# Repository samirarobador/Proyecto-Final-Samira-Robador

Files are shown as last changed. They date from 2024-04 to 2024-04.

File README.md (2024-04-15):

# Brazo Robótico Dispensador de Sustancias Químicas

El Laboratorio de Alta Complejidad de la Universidad Nacional de Chilecito, desempeña un papel vital en la ejecución de  análisis esenciales para la investigación y empresas. No obstante, actualmente  se enfrenta a limitaciones significativas relacionadas con la dosificación manual de sustancias químicas. Con el objetivo de abordar esta problemática y potenciar la precisión como así también la eficiencia en la manipulación de sustancias químicas, este proyecto propone automatizar el proceso mediante un brazo robótico especializado. Esta solución mejorará la precisión y eficiencia en la manipulación de sustancias químicas, agilizando análisis y reduciendo las posibilidades de errores. 

Este repositorio contiene el código fuente para un sistema de control de dosificación de sustancias químicas implementado con Python y Django, y con una interfaz de usuario basada en HTML, CSS y JavaScript. Permite la manipulación y control remoto de un robot dosificador a través de una interfaz web.

## Comenzando

Estas instrucciones te permitirán obtener una copia del proyecto en funcionamiento en tu máquina local para propósitos de desarrollo y pruebas.

### Prerrequisitos

Necesitarás Python y Django instalados en tu sistema para poder ejecutar el proyecto. Asegúrate también de tener instalado Git para clonar el repositorio.

```bash
# Instalar Git
sudo apt-get install git

# Instalar Python (el comando puede variar dependiendo de tu sistema operativo)
sudo apt-get install python3

# Instalar Django
pip install django
```

## Instalación
Clona el repositorio en tu máquina local usando Git.

```bash
git clone https://github.com/samirarobador/Proyecto-Final-Samira-Robador.git
cd Proyecto-Final-Samira-Robador/mi_proyecto
```

## Levantar la Aplicación
Para iniciar la aplicación, ejecuta el servidor de desarrollo de Django con el siguiente comando:

```bash
python manage.py runserver
```

Una vez que el servidor esté funcionando, podrás acceder a la aplicación a través de tu navegador web en localhost:8000/.

## Despliegue
Este proyecto está configurado para ser ejecutado en un entorno de desarrollo. Para despliegues en producción, se deben realizar configuraciones adicionales, siguiendo las mejores prácticas de seguridad y rendimiento recomendadas por Django.

## Construido Con
- Python - El lenguaje de programación utilizado.
- Django - El framework web.
- HTML5, CSS3, y JavaScript - Para la interfaz de usuario.

## Autor

([Samira Robador](https://github.com/samirarobador)) - Trabajo Final

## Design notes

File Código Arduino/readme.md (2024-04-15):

# Configuración de placa ESP32

Este repositorio contiene el archivo de configuración `.ino` para la manipulación de un brazo robótico. Este script en particular se encarga de configurar y manejar el brazo robótico, conectarlo a la red Wi-Fi, y ajustar parámetros esenciales para su operación.

## Contenido del Repositorio

- **RoboticArm.ino**: Archivo principal que contiene todo el código necesario para la configuración inicial del brazo robótico, la conexión Wi-Fi y la manipulación de sus articulaciones.

## Requisitos

Para utilizar este archivo, necesitarás:

- **Arduino IDE**: Para cargar el código al microcontrolador.
- **Módulo ESP32**: Este código está diseñado para microcontroladores ESP32.

## Instalación

1. Descarga e instala el Arduino IDE desde [la página oficial de Arduino](https://www.arduino.cc/en/software).
2. Clona este repositorio en tu computadora local o descarga el archivo `RobotDispensador.ino` directamente.
3. Abre el archivo `RobotDispensador.ino` con Arduino IDE.
4. Conecta tu módulo ESP32 a tu computadora mediante un cable USB.
5. Selecciona el modelo correcto de tu ESP32 en el menú de Herramientas > Placa de Arduino IDE.
6. Compila y sube el código al ESP32 seleccionando "Subir" en el Arduino IDE.

## Configuración de Wi-Fi

El archivo `RobotDispensador.ino` contiene secciones claramente marcadas para configurar tu red Wi-Fi. Asegúrate de actualizar las siguientes líneas con tus datos de acceso a Wi-Fi:

```c++
const char* ssid = "TU_SSID";
const char* password = "TU_CONTRASEÑA";

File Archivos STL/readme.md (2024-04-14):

# Brazo Robótico 3D

Este repositorio contiene los archivos STL necesarios para imprimir un el Brazo Robótico Dispensador de Sustancias Químicas completo en una impresora 3D. Cada archivo representa una pieza específica del brazo robótico, diseñado para ser fácilmente ensamblable y funcional, además de las estructuras adicionales detalladas en el Proyecto Final.

## Contenido del Repositorio

Dentro de este repositorio, encontrarás los siguientes archivos STL:

- `basefija.stl` - La base del brazo robótico.
- `basegiratoria.stl` - La base giratoria del brazo robótico.
- `antebrazo.stl` - El antebrazo del brazo robótico.
- `brazo.stl` - La articulación del brazo.
- `muñeca.stl` - La muñeca, que conecta el brazo con la manguera de dispensación.
- `soportegradilla.stl` - El soporte gradilla, corresponde a la estructura adicional desarrollada para la grilla original.
- `basegradillaizq.stl` - La basegradilla izq corresponde a la estructura básica de la gradilla en coordenadas polares.
- `basegradillader.stl` - La basegradilla der corresponde a la estructura básica de la gradilla en coordenadas polares.
- `gradillaizq.stl` - La gradilla izq corresponde a la estructura principal de la gradilla en coordenadas polares.
- `gradillader.stl` - La gradilla der corresponde a la estructura principal de la gradilla en coordenadas polares.

## Instrucciones de Impresión

### Materiales Recomendados

- PLA/ABS para una mayor durabilidad.
- Soportes para algunas piezas que podrían requerirlo debido a la complejidad de su diseño.

### Configuración de Impresión

- Resolución: 0.2 mm para un buen equilibrio entre tiempo de impresión y detalle.
- Relleno: 20% para asegurar la durabilidad sin usar demasiado material.
- Soportes: Según sea necesario, especialmente para piezas con voladizos o puentes.

## Montaje

Después de imprimir todas las piezas, siga las instrucciones paso a paso para el ensamblaje del brazo robótico. Se recomienda verificar y limar cualquier parte que pueda tener excesos de material o hilos para un ensamblaje suave.

## Contacto

Si tiene preguntas o necesita ayuda con los archivos, no dude en contactarme a [samirarobador@gmail.com](mailto:samirarobador@gmail.com).

---

Espero que disfrute construyendo y utilizando este brazo robótico. Por favor, comparta sus modificaciones y mejoras para que otros puedan beneficiarse de su trabajo.

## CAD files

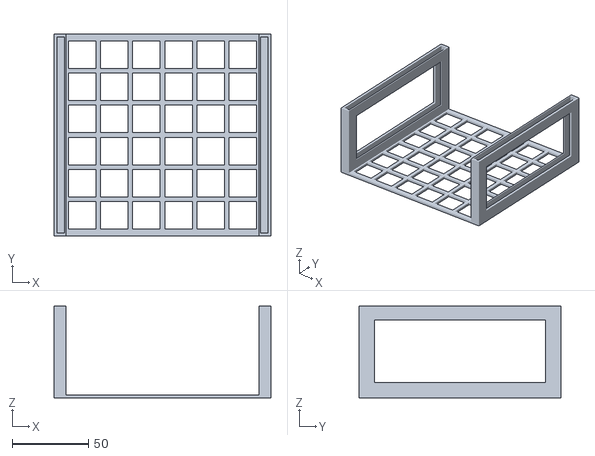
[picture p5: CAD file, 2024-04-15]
Archivos STL/Soporte adaptado Gradilla.stl
142.0 x 132.0 x 60.0

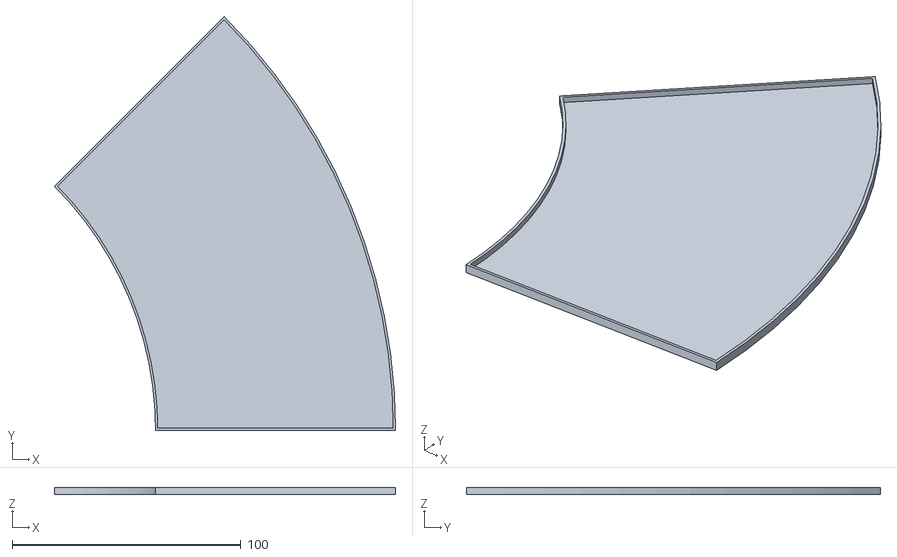
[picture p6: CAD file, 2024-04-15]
Archivos STL/Base Gradilla Nueva.stl
149.2 x 181.0 x 3.00

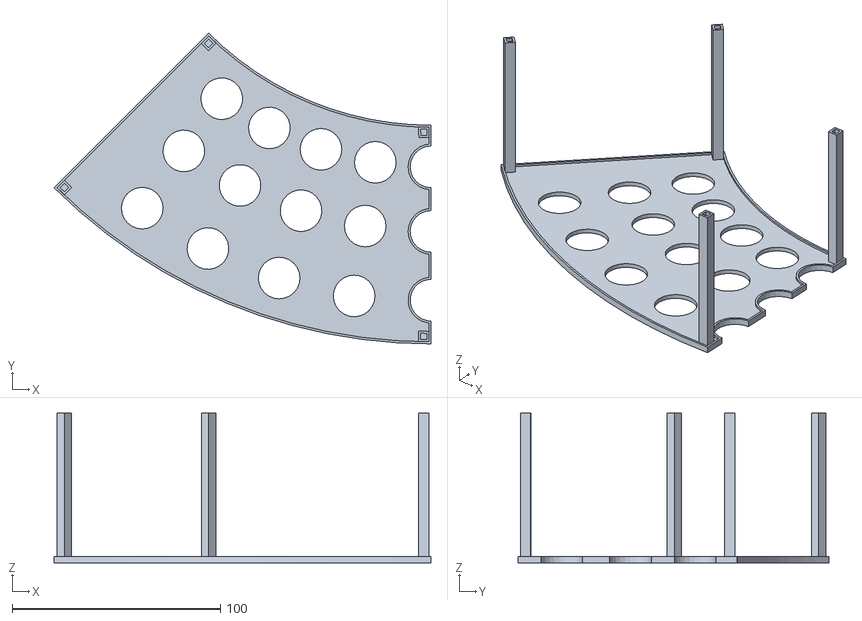
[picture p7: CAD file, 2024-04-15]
Archivos STL/Gradilla Nueva 2.stl
181.0 x 149.2 x 72.0

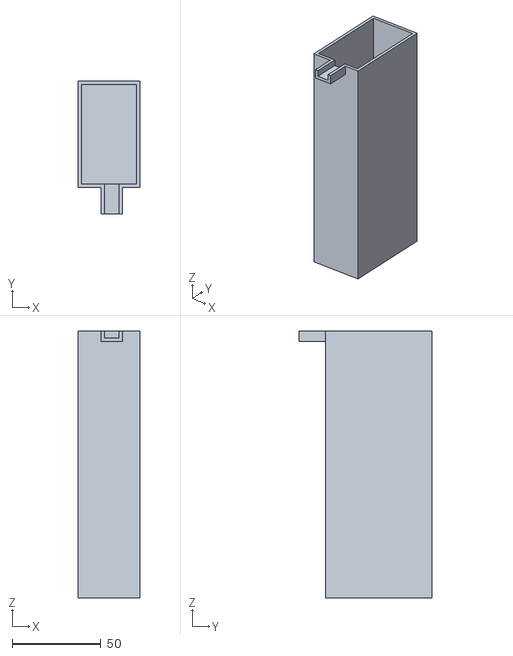
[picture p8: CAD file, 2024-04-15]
Archivos STL/Vaso Purgado.stl
35.0 x 75.0 x 150.0

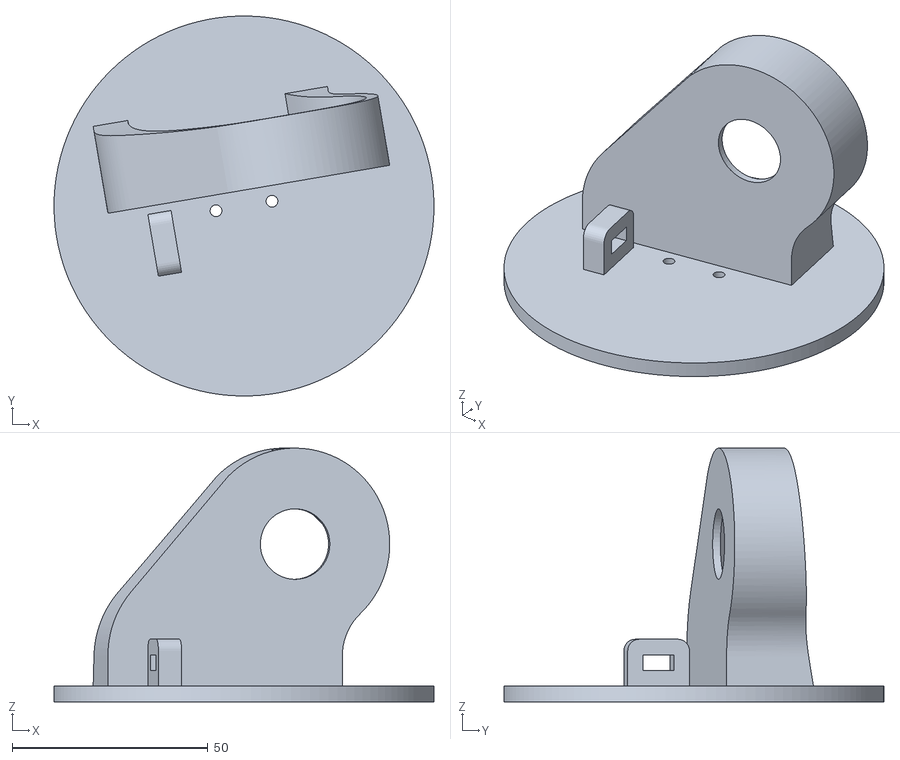
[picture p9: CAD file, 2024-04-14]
Archivos STL/Base Giratoria.stl
97.0 x 97.0 x 64.8

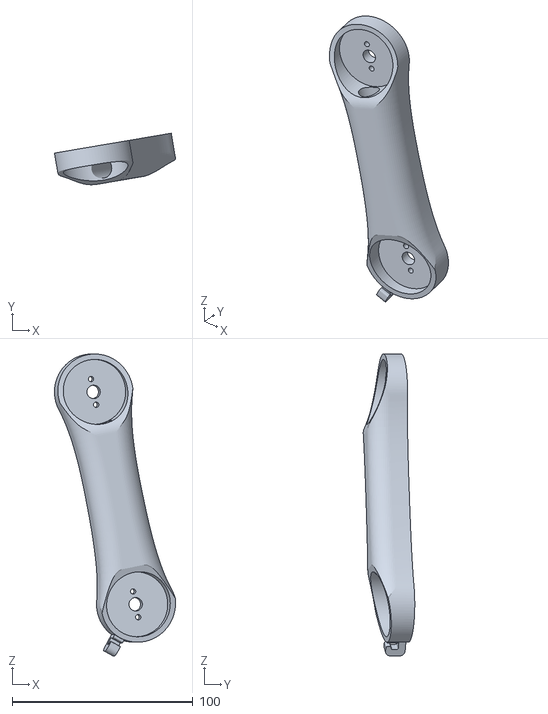
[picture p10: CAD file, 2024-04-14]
Archivos STL/Brazo.stl
67.1 x 28.6 x 167.3

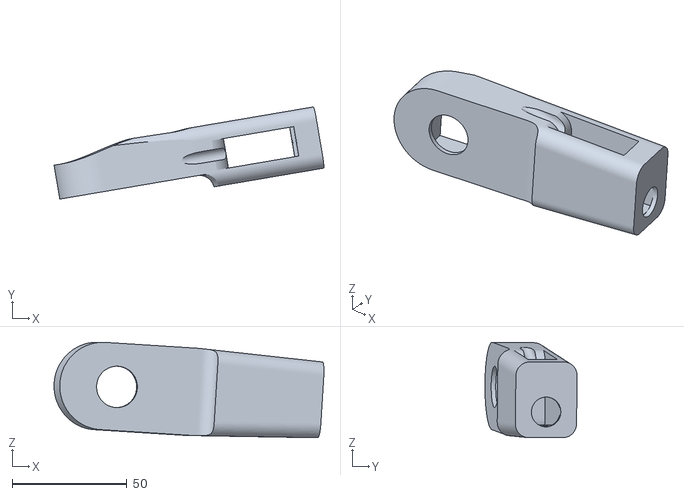
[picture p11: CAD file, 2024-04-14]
Archivos STL/Antebrazo.stl
117.4 x 40.1 x 41.5

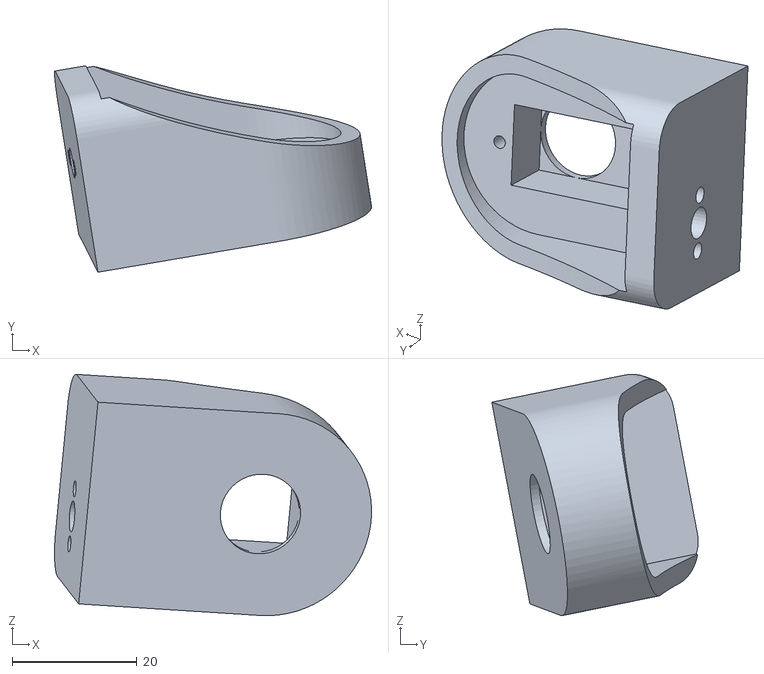
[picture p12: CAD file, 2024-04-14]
Archivos STL/Extremo.stl
50.7 x 33.0 x 38.6

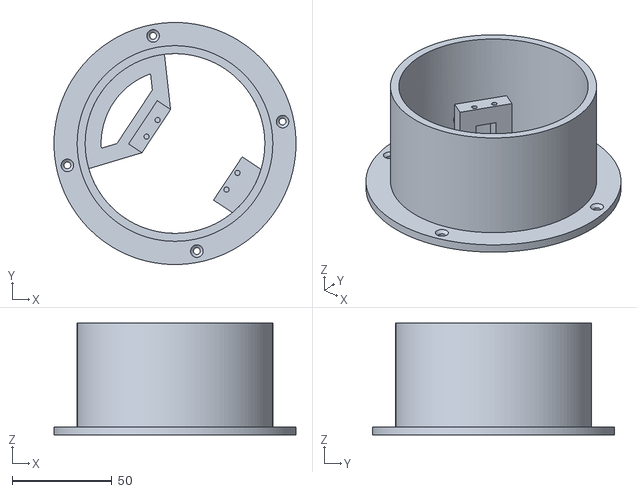
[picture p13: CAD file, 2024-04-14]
Archivos STL/Base.stl
121.2 x 121.2 x 56.0

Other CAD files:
Archivos STL/Gradilla Nueva 1.stl

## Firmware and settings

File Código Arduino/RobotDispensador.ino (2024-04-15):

#include <WiFi.h>
#include <ESPAsyncWebServer.h>
#include <ESP32Servo.h>
#include <HTTPClient.h>
#include <stdlib.h>
#include <math.h>
#include <stdio.h>

const char *ssid = "aquinombredered";
const char *password = "aquipassdered";

const int bombaPin = 25; // Pin al que está conectado Servo1

const int servoPin1 = 12; // Pin al que está conectado Servo1
const int servoPin2 = 14; // Pin al que está conectado Servo2
const int servoPin3 = 27; // Pin al que está conectado Servo3
const int servoPin4 = 26; // Pin al que está conectado Servo4

float q1Valor = 85;
float q2Valor = 160;
float q3Valor = 162;
float q4Valor = 87;

int maxServo = 2540;
int minServo = 440;


Servo servo1; // Declarar el objeto servo1
Servo servo2; // Declarar el objeto servo2
Servo servo3; // Declarar el objeto servo2
Servo servo4; // Declarar el objeto servo2
HTTPClient http;
AsyncWebServer server(80);

void moverGradualmenteServo(Servo &servo, float targetAngle) {
  float currentAngle = servo.read(); // Leer el ángulo actual del servo
  Serial.print("Valor actual del Servo: ");
  Serial.println(currentAngle);
  float step = (targetAngle > currentAngle) ? 1 : -1; // Determinar el paso de incremento o decremento

  // Mover gradualmente el servo hacia el ángulo deseado
  while (currentAngle != targetAngle) {
    currentAngle = currentAngle + step; // Incrementar o decrementar el ángulo actual
    servo.write(currentAngle); // Enviar el nuevo ángulo al servo
    delay(10); // Pequeña pausa para suavizar el movimiento (ajustar según necesites)
    Serial.print("Moviendo: ");
    Serial.println(currentAngle);

  }
}

void moverGradualmenteServos(Servo &servo1, Servo &servo2, Servo &servo3, Servo &servo4, float q1, float q2, float q3, float q4) {
  float q1Step = (q1 > q1Valor) ? 1 : -1; // Determinar el paso de incremento o decremento para servo1
  float q2Step = (q2 > q2Valor) ? 1 : -1; // Determinar el paso de incremento o decremento para servo2
  float q3Step = (q3 > q3Valor) ? 1 : -1; // Determinar el paso de incremento o decremento para servo3
  float q4Step = (q4 > q4Valor) ? 1 : -1; // Determinar el paso de incremento o decremento para servo4
  int tiempo = 9;
  int falta1 = (q1 - q1Valor);
  int falta2 = (q2 - q2Valor);
  int falta3 = (q3 - q3Valor);
  int falta4 = (q4 - q4Valor);

  Serial.printf("\nDel servo 1 falta %d\n", falta1);
  Serial.printf("\nDel servo 2 falta %d\n", falta2);
  Serial.printf("\nDel servo 3 falta %d\n", falta3);
  Serial.printf("\nDel servo 4 falta %d\n", falta4);

  // Determinar el número máximo de iteraciones basado en el servo que debe moverse más
  int maxIterations = max(abs(q1 - q1Valor), max(abs(q2 - q2Valor), max(abs(q3 - q3Valor), abs(q4 - q4Valor))));

  for (int i = 0; i < maxIterations; i++) {
    if (fabs(q1 - q1Valor) > 0.0001) {
      //servo1.write(q1Valor + q1Step); // Mover servo1 un grado
      servo1.writeMicroseconds(map(q1Valor + q1Step, 0, 180, minServo, maxServo));
      q1Valor += q1Step;
    }
    if (fabs(q2 - q2Valor) > 0.0001) {
      //servo2.write(q2Valor + q2Step); // Mover servo2 un grado
      servo2.writeMicroseconds(map(q2Valor + q2Step, 0, 180, minServo, maxServo));
      q2Valor += q2Step;
    }
    if (fabs(q3 - q3Valor) > 0.0001) {
      //servo3.write(q3Valor + q3Step); // Mover servo3 un grado
      servo3.writeMicroseconds(map(q3Valor + q3Step, 0, 180, minServo, maxServo));
      q3Valor += q3Step;
    }
    if (fabs(q4 - q4Valor) > 0.0001) {
      //servo4.write(q4Valor + q4Step); // Mover servo4 un grado
      servo4.writeMicroseconds(map(q4Valor + q4Step, 0, 180, minServo, maxServo));
      q4Valor += q4Step;
    }
    delay(tiempo); // Pequeña pausa para suavizar el movimiento (ajustar según necesites)
  }

  if(abs(falta1) > 0){
    for (int i = 0; i < 8; i++){
      q1Valor -= 1;
      servo1.writeMicroseconds(map(q1Valor, 0, 180, minServo, maxServo));
      delay(tiempo);
    }
  
     for (int i = 0; i < 8; i++){
      q1Valor += 1;
      servo1.writeMicroseconds(map(q1Valor, 0, 180, minServo, maxServo));
      delay(tiempo);
    }
  }

    if(abs(falta2) > 0){
    for (int i = 0; i < 8; i++){
      q2Valor += 1;
      servo2.writeMicroseconds(map(q2Valor, 0, 180, minServo, maxServo));
      delay(tiempo);
    }
  
     for (int i = 0; i < 8; i++){
      q2Valor -= 1;
      servo2.writeMicroseconds(map(q2Valor, 0, 180, minServo, maxServo));
      delay(tiempo);
    }
  }


    if(abs(falta3) > 0){
    for (int i = 0; i < 8; i++){
      q3Valor -= 1;
      servo3.writeMicroseconds(map(q3Valor, 0, 180, minServo, maxServo));
      delay(tiempo);
    }
  
     for (int i = 0; i < 8; i++){
      q3Valor += 1;
      servo3.writeMicroseconds(map(q3Valor, 0, 180, minServo, maxServo));
      delay(tiempo);
    }
  }


    if(abs(falta4) > 0){
    for (int i = 0; i < 10; i++){
      q4Valor += 1;
      servo4.writeMicroseconds(map(q4Valor, 0, 180, minServo, maxServo));
      delay(tiempo);
    }
  
     for (int i = 0; i < 10; i++){
      q4Valor -= 1;
      servo4.writeMicroseconds(map(q4Valor, 0, 180, minServo, maxServo));
      delay(tiempo);
    }
  }

}


void setup() {
  pinMode(bombaPin, OUTPUT);
  digitalWrite(bombaPin, LOW);
  Serial.begin(9600);
  // Conectar a la red WiFi
  WiFi.begin(ssid, password);
  while (WiFi.status() != WL_CONNECTED) {
    delay(1000);
    Serial.println("Conectando a la red WiFi...");
  }
  Serial.println("Conexión exitosa a la red WiFi");

  // Imprimir la dirección IP asignada
  Serial.print("Dirección IP asignada: ");
  Serial.println(WiFi.localIP());

  String peticion = "http://192.168.0.161:8000/recibir_mensaje/?mensaje=" + WiFi.localIP().toString();

  Serial.println(peticion);

  http.begin(peticion.c_str());

  Serial.println(peticion);
  int httpCode = http.GET();

  Serial.println("Respuesta");

  Serial.println(httpCode);



  servo1.attach(servoPin1); // Inicializar servo1 en el pin especificado
  servo2.attach(servoPin2); // Inicializar servo2 en el pin especificado
  servo3.attach(servoPin3); // Inicializar servo3 en el pin especificado
  servo4.attach(servoPin4); // Inicializar servo4 en el pin especificado

  servo1.write(q1Valor);
  servo2.write(q2Valor);
  servo3.write(q3Valor);
  servo4.write(q4Valor);

  moverGradualmenteServos(servo1, servo2, servo3, servo4, q1Valor+5, q2Valor+5, q3Valor+5, q4Valor+5);




  server.on("/ping", HTTP_GET, [](AsyncWebServerRequest * request) {
    AsyncResponseStream *response = request->beginResponseStream("text/plain");
    response->addHeader("Access-Control-Allow-Origin", "*");
    response->print("pong");
    //Serial.println("Peticion GET recibida");
    request->send(response);
  });


  server.on("/espera", HTTP_GET, [](AsyncWebServerRequest * request) {
    AsyncResponseStream *response = request->beginResponseStream("text/plain");
    response->addHeader("Access-Control-Allow-Origin", "*");
    delay(1000);
    //Serial.println("Peticion GET recibida");
    request->send(response);
  });


  // Rutas y controladores para peticiones GET
  server.on("/", HTTP_GET, [](AsyncWebServerRequest * request) {
    //Serial.println("Peticion GET recibida");
    request->send(200, "text/plain", "Hola desde ESP32!");
  });

  // Rutas y controladores para peticiones POST
  server.on("/post", HTTP_POST, [](AsyncWebServerRequest * request) {
    //Serial.println("Peticion POST recibida");
    String message;
    if (request->hasParam("message", true)) {
      message = request->getParam("message", true)->value();
    }
    //Serial.println("Mensaje recibido: " + message);
    request->send(200, "text/plain", "Mensaje recibido: " + message);
  });

  // Rutas y controladores para peticiones POST
  server.on("/bombaagua", HTTP_POST, [](AsyncWebServerRequest * request) {
    //Serial.println("Peticion POST recibida para mover el Servo 1");
    if (request->hasParam("valor", true)) {
      String tiempo = request->getParam("valor", true)->value();
      float valor = atof(tiempo.c_str());
      Serial.println(valor);
      digitalWrite(bombaPin, HIGH);
      delay(valor);
      digitalWrite(bombaPin, LOW);
      request->send(200, "text/plain", "Bomba encendida" + tiempo + " milisegundos");
    } else {
      request->send(400, "text/plain", "Parámetro de tiempo (valor) faltante.");
    }

  });

  // Rutas y controladores para peticiones POST
  server.on("/servo1", HTTP_POST, [](AsyncWebServerRequest * request) {
    //Serial.println("Peticion POST recibida para mover el Servo 1");
    if (request->hasParam("valor", true)) {
      String angleStr = request->getParam("valor", true)->value();
      float valor = atof(angleStr.c_str());
      //Serial.println(valor);
      moverGradualmenteServo(servo1, valor);
      request->send(200, "text/plain", "Servo1 movido a " + angleStr + " grados.");
    } else {
      request->send(400, "text/plain", "Parámetro de ángulo faltante.");
    }
  });

  // Rutas y controladores para peticiones POST
  server.on("/servo2", HTTP_POST, [](AsyncWebServerRequest * request) {

    //Serial.println("Peticion POST recibida para mover el Servo 3");
    if (request->hasParam("valor", true)) {
      String angleStr = request->getParam("valor", true)->value();
      float valor = atof(angleStr.c_str());
      //Serial.println(valor);
      moverGradualmenteServo(servo2, valor);
      request->send(200, "text/plain", "Servo2 movido a " + angleStr + " grados.");
    } else {
      request->send(400, "text/plain", "Parámetro de ángulo faltante.");
    }
  });

  // Rutas y controladores para peticiones POST
  server.on("/servo3", HTTP_POST, [](AsyncWebServerRequest * request) {

    //Serial.println("Peticion POST recibida para mover el Servo 3");
    if (request->hasParam("valor", true)) {
      String angleStr = request->getParam("valor", true)->value();
      float valor = atof(angleStr.c_str());
      //Serial.println(valor);
      moverGradualmenteServo(servo3, valor);
      request->send(200, "text/plain", "Servo3 movido a " + angleStr + " grados.");
    } else {
      request->send(400, "text/plain", "Parámetro de ángulo faltante.");
    }
  });

  // Rutas y controladores para peticiones POST
  server.on("/servo4", HTTP_POST, [](AsyncWebServerRequest * request) {

    //Serial.println("Peticion POST recibida para mover el Servo 4");
    if (request->hasParam("valor", true)) {
      String angleStr = request->getParam("valor", true)->value();
      float valor = atof(angleStr.c_str());
      //Serial.println(valor);
      moverGradualmenteServo(servo4, valor);
      request->send(200, "text/plain", "Servo4 movido a " + angleStr + " grados.");
    } else {
      request->send(400, "text/plain", "Parámetro de ángulo faltante.");
    }
  });
  server.begin();


  // Rutas y controladores para peticiones POST
  server.on("/todos", HTTP_POST, [](AsyncWebServerRequest * request) {

    //Serial.println("Peticion POST recibida para mover el Servo 4");
    if (request->hasParam("q1", true) && request->hasParam("q2", true) && request->hasParam("q3", true) && request->hasParam("q4", true)) {
      String angleStr1 = request->getParam("q1", true)->value();
      String angleStr2 = request->getParam("q2", true)->value();
      String angleStr3 = request->getParam("q3", true)->value();
      String angleStr4 = request->getParam("q4", true)->value();
      Serial.println(angleStr3);
      float q1 = atof(angleStr1.c_str());
      float q2 = atof(angleStr2.c_str());
      float q3 = atof(angleStr3.c_str());
      float q4 = atof(angleStr4.c_str());

      Serial.print(q1, 6);
      Serial.println("");
      Serial.print(q2, 6);
      Serial.println("");
      Serial.print(q3, 6);
      Serial.println("");
      Serial.print(q4, 6);
      Serial.println("");
      /*moverGradualmenteServo(servo1, q1+90);
        moverGradualmenteServo(servo2, q2+30);
        moverGradualmenteServo(servo3, 120-q3);
        moverGradualmenteServo(servo4, -(q2-90+q3));
      */

      moverGradualmenteServos(servo1, servo2, servo3, servo4, q1 + 45, q2 + 30, 30 - q3, -(q2 - 90 + q3));

      request->send(200, "text/plain", "Todas las articulaciones movidas");
    } else {
      request->send(400, "text/plain", "Falta algún parametro");
    }
  });
  server.begin();
}



void loop() {
}

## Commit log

2024-03-03 cambio en el readme
2024-03-03 modifique el readme
2024-03-03 agregado de endpoint
2024-03-03 funcion que recibe numeros
2024-04-13 agregado de gradilla
2024-04-14 Creación de Carpeta de Adjuntos
2024-04-14 Agregado de stl y readme
    [Base Giratoria.stl, Base.stl, Brazo 1.stl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]
2024-04-15 agregado de menu
2024-04-15 agregadode arduino
